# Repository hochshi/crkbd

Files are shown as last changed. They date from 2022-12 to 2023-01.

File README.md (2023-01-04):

# Corne keyboard

The Corne Choc-mini keyboard is a split keyboard with 3x5 column staggered keys
and 3 thumb keys, based on [Corne](https://github.com/foostan/crkbd). The inspiration came from David Barr's [Choc-Spaced-Corne](https://github.com/davidphilipbarr/Choc-Spaced-Corne).

## Lineup
- corne-light: 
  Light-weight Corne for choc-mini switches with choc spacing (Easy build with a simple PCB).
- corne-light-track-point: 
  Light-weight Corne for choc-mini switches with choc spacing and a trackpoint under the right thumb (or far-index) (Not ready yet).

### Future Plans
The next iteration will replace one of the micro-controllers with an IO expander

## Photos
light_01
light_02

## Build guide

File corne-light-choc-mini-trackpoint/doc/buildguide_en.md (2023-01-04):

# Build Guide

This is the Corne Light build guide.
The build guide differs depending on the version of your board,
so please choose your own from the following.

- [v1 build guide](https://github.com/foostan/crkbd/blob/master/corne-light/doc/v1/buildguide_en.md)
- [v2 low-edition build guide](https://github.com/foostan/crkbd/blob/master/corne-light/doc/v2/buildguide_low_edition_en.md)

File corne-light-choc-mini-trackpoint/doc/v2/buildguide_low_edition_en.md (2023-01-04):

# Build Guide

This is the build guide for Corne Light v2 Low edition.

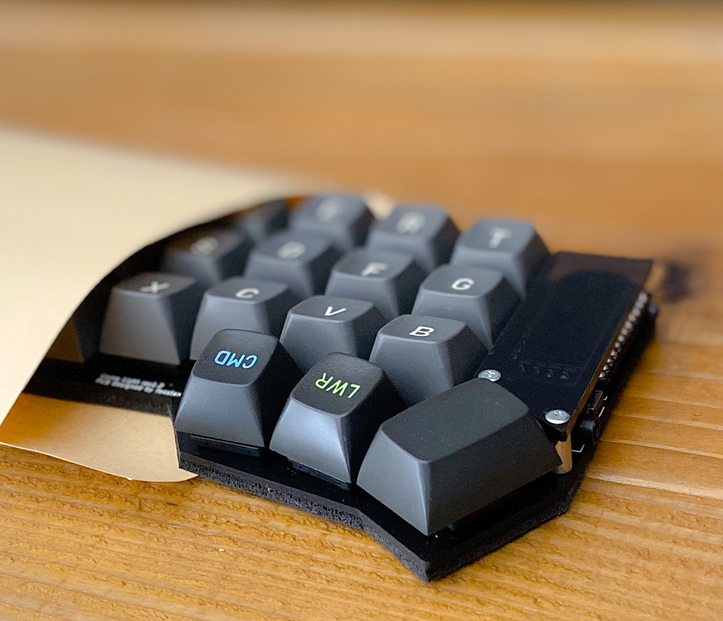
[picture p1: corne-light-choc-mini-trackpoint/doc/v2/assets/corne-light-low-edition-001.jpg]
corne-light-low-edition-001

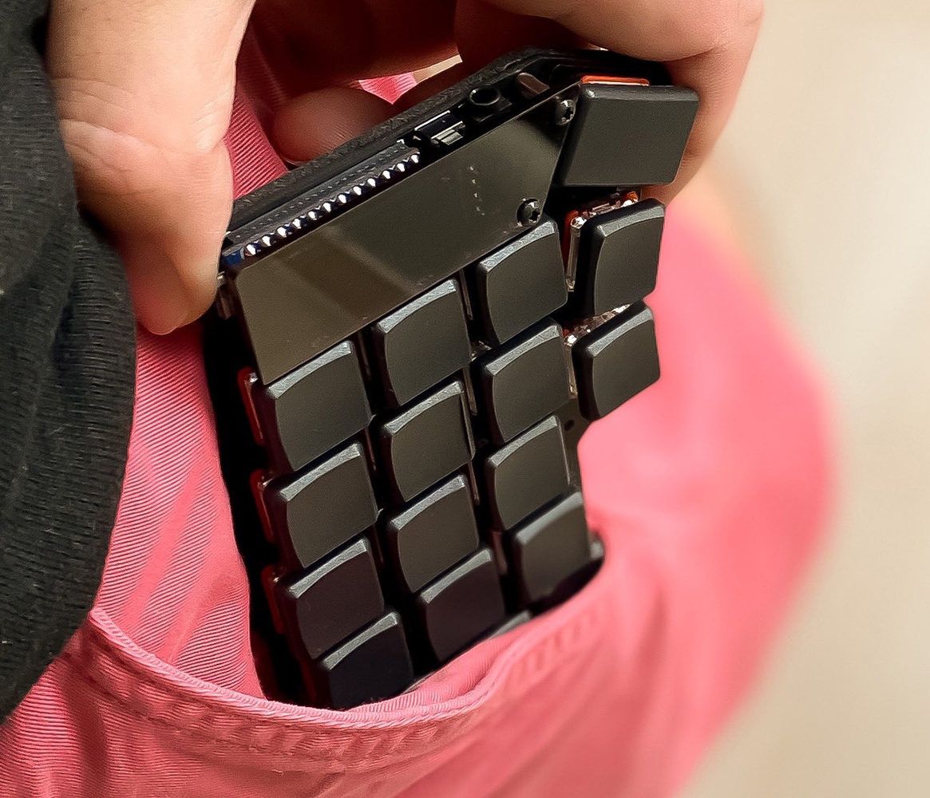
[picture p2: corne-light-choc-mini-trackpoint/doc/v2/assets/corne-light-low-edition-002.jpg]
corne-light-low-edition-002

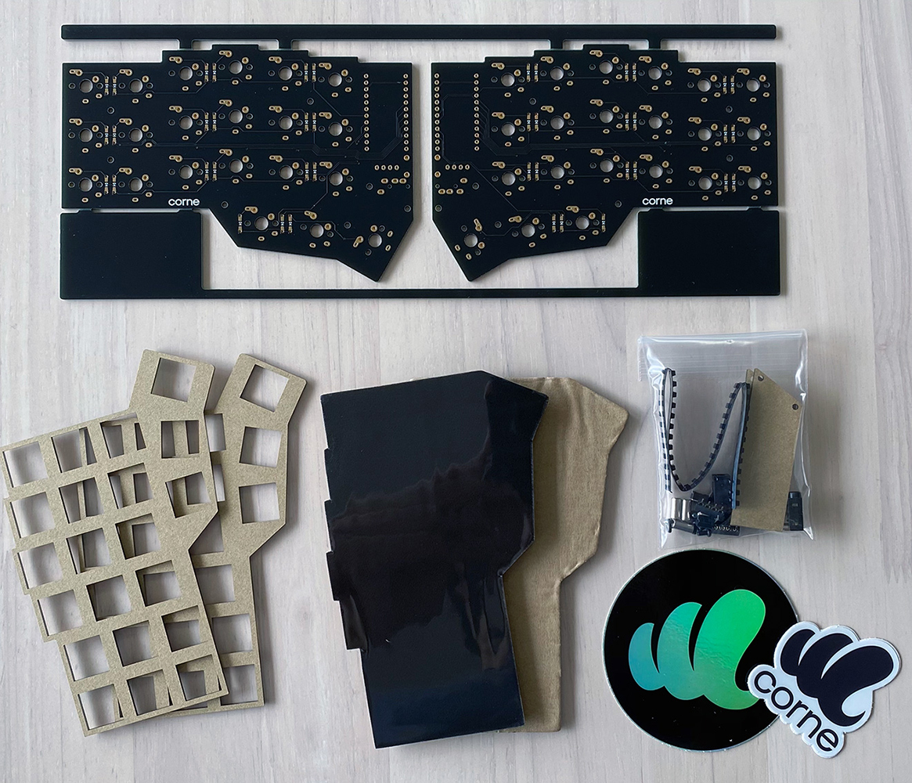
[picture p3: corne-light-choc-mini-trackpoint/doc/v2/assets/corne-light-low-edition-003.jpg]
corne-light-low-edition-003


## Parts

### Required

| Name | Count | Remarks |
|:-|:-|:-|
| PCB | 1 set | |
| Top plate (acrylic) 2mm | 2 sheets | |
| Bottom foam | 2 sheets | Special foam is cut out with a special mold |
| OLED protective plate | 2 sheets | |
| ProMicro | 2 sheets | |
| TRRS jack | 2 | |
| Tact switch | 2 | |
| Diodes | 42 | Recommended SMD Parts |
| Key switches | 42 | Kailh Choc v1 or v2 recommended |
| Keycaps | 42 pcs | 1u 40 pcs, 1.5u 2 pcs |
| Spacer M2 9mm | 4 pieces | |
| Screw M2 4mm | 8 screws | |
| TRRS (4 poles) cable | 1 | TRS (3 poles) cable is also acceptable |
| Micro USB cable | 1 | |

### Optional

| Name | Count | Remarks |
|:-|:-|:-|
| OLED module | 2 sheets | |
| Pin header for OLED module 4 series 1.5mm | 2 | |
| 4 pin sockets for OLED module 2.5mm | 2 | |

## Advance preparation

If you build the firmware yourself,
it takes time to prepare the environment,
so it is recommended to start first. \
See <https://github.com/foostan/crkbd/blob/master/doc/firmware_en.md>
for more information.

## Verification

The PCB for Corne Light v2 is as follows.
Make sure it is the same as your PCB.

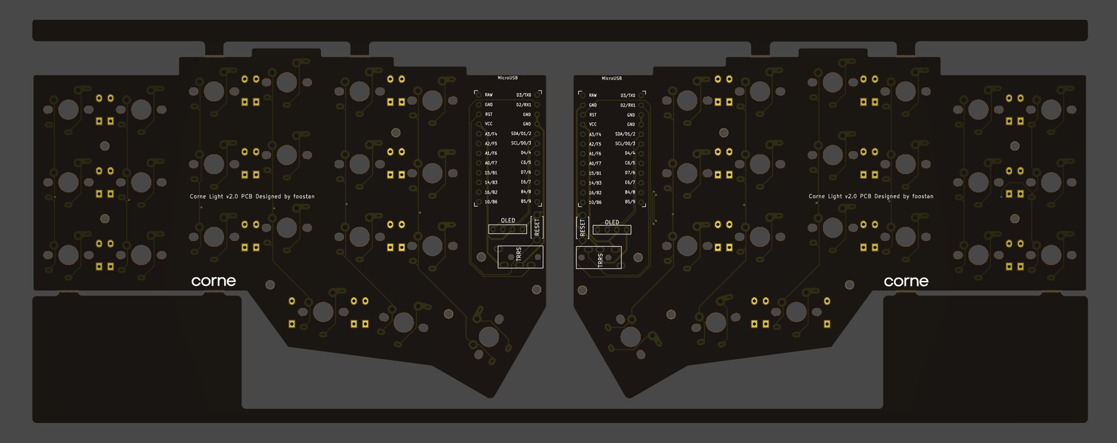
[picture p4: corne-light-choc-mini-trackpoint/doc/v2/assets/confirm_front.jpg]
confirm_front


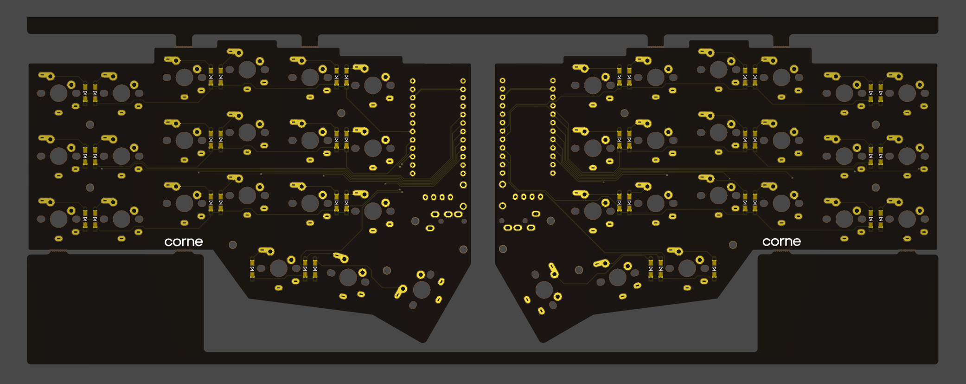
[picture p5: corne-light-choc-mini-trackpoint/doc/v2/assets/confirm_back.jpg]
confirm_back


The PCB comes with a frame for manufacturing reasons.
You can fold it by hand to remove it, but if it is difficult,
make a cut in the joint \* with a cutter or similar,
to make it easier to remove.
In addition, the joint can be cleaned with a file.

\* *Joint part: There are a total of 8 parts,
which are marked in red in the image below.*

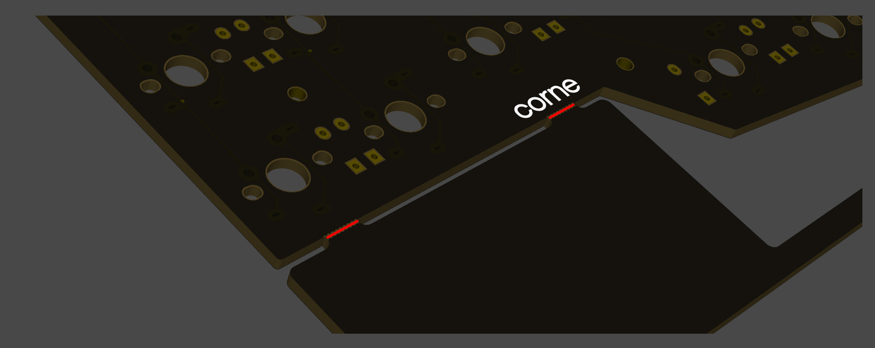
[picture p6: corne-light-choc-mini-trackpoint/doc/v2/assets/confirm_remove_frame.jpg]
confirm_remove_frame


## Assembly

### Diodes

Solder diodes for SMD components.
Since SMD parts are very small,
it is convenient to have tweezers and counter-acting tweezers.

**The diode has a fixed mounting direction**,
so solder it so that the "|" mark on the part faces the "|" on the diode mark "|◁".
In addition, Corne's PCB has all the same diode mounting orientations.

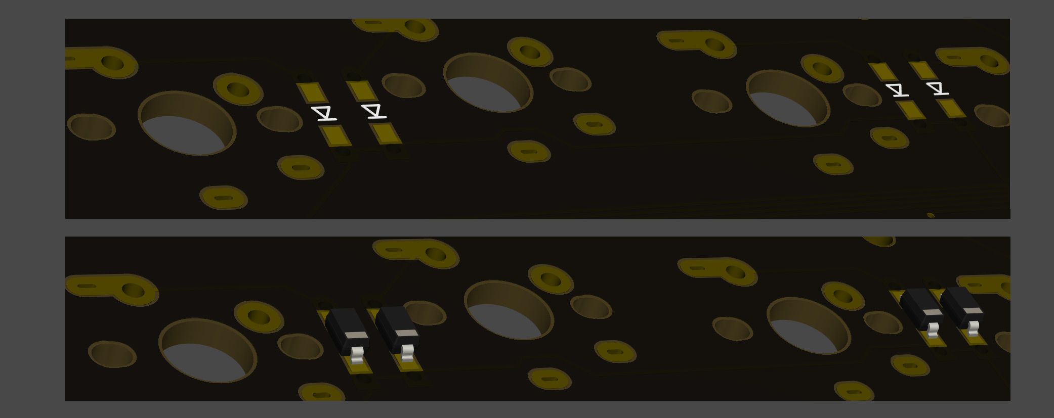
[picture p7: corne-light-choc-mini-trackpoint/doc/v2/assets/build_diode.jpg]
build_diode


<details>
<summary>TIPS: Tips for installing SMD parts</summary>

The trick is to attach the SMD parts, but first, as a spare solder,
put the solder on only one side of the pad.

tips_building_smd_01

Next, solder one leg of the diode so that the spare solder melts.
At this time, it is recommended to use reverse-action tweezers,
because you can hold the chip parts firmly without exerting force
and you can concentrate on alignment and soldering.
Also, if the soldering iron is too hot or the solder is touched too much,
the flux contained in the solder may evaporate and form a clean pile of solder,
but it can be repaired later,
so at this point you should only care about attaching parts.
It's okay.

tips_building_smd_02

It is okay if the diode does not float when viewed from the side
when one foot is attached.
If it floats, press the diode with tweezers or your fingers
and reheat the soldered part with a soldering iron to clean it.

tips_building_smd_03

Then solder the other one.
Be careful not to apply too much,
as a small amount of solder is sufficient.
If you apply too much, you can remove it with a blotting wire
or by scooping it with a soldering iron.

If the amount of solder on the preliminary solder side is small,
additional soldering is performed, and if it is a mountain,
apply flux from above and heat it to clean it.

tips_building_smd_04

</details>

The diode is completed by soldering 42 pieces in total on the left and right.

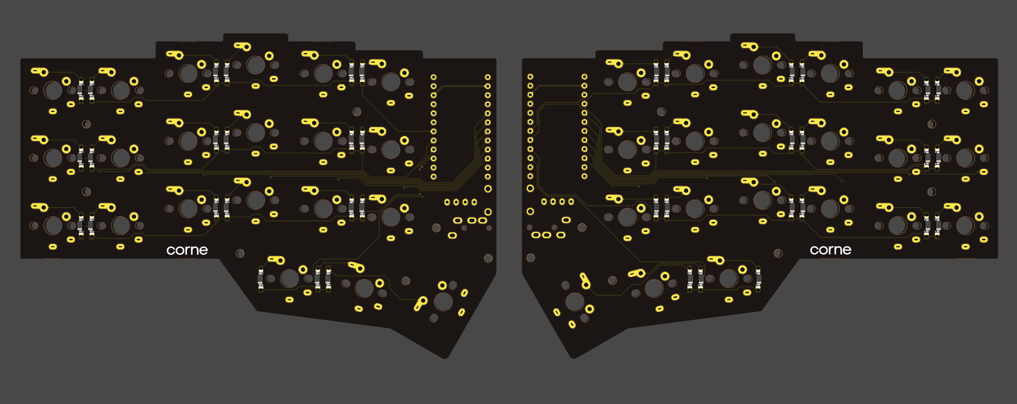
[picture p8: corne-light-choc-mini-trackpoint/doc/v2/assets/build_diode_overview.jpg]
build_diode_overview


### TRRS jack, reset switch, pin socket for OLED

Solder the TRRS jack, reset switch (tact switch),
and OLED pin socket as shown in the picture below.

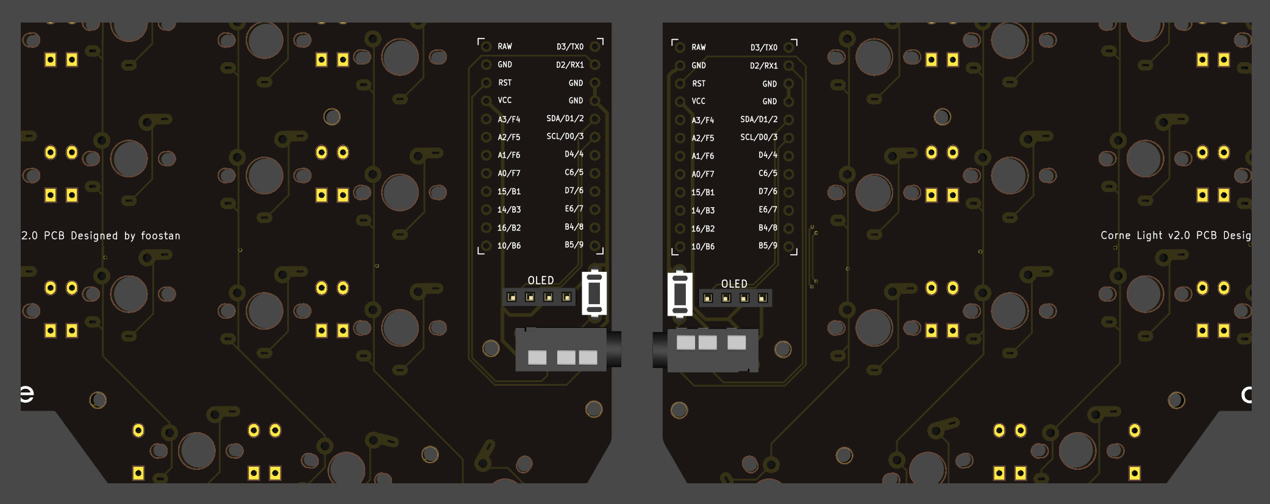
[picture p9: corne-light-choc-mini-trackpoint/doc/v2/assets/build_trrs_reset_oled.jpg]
build_trrs_reset_oled


Since it is a part that easily slips off,
you can solder it while holding the part by hand,
or fix it with masking tape and then solder it.

### ProMicro

Solder ProMicro in the following orientation

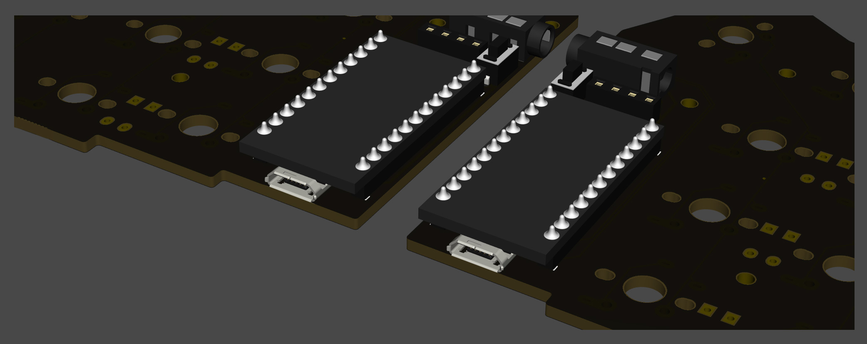
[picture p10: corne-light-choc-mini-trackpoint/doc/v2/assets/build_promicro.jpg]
build_promicro


If you use spring-loaded pin headers (e.g. Conthrough),
you do not need to solder the back side.
Please refer to the [Helix Build Guide](
https://github.com/MakotoKurauchi/helix/blob/master/Doc/buildguide_en.md#pro-micro)
for details on how to use spring-loaded pin headers.

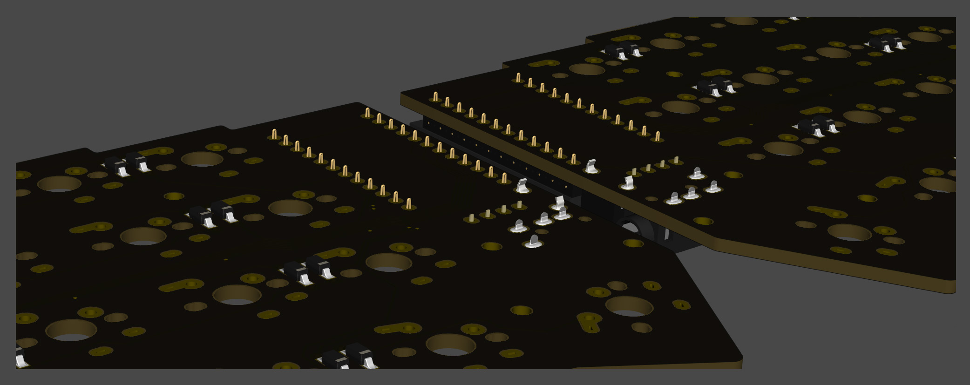
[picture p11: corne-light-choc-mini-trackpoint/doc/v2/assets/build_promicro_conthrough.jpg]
build_promicro_conthrough


### OLED module

Insert the pin header into the pin socket for OLED first,
and then solder the pin header and OLED module.
At this time, the OLED module is easy to float,
so be careful not to float it while pressing it with your finger.

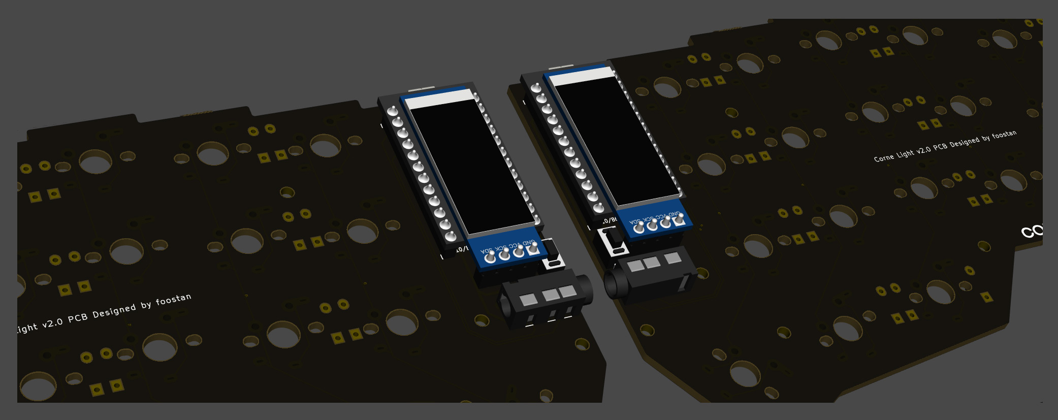
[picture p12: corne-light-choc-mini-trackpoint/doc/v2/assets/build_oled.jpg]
build_oled


### Firmware

Write the firmware to ProMicro by referring to the following. \
<https://github.com/foostan/crkbd/blob/master/doc/firmware_en.md>

### Operation check

We recommend that you check the operation when the ProMicro and OLED module are attached.
If you do it at the very end, it will be difficult to isolate the problem.

To check the operation,
connect the left hand side to the PC with MicroUSB,
and connect the left hand side and the right hand side with the TRRS cable.
Since there may be defects such as jacks,
be sure to connect the left and right instead of one by one
before checking the operation.
If it is done correctly so far,
if you short the pad to attach the PCB socket with tweezers etc.,
the key pressed on the OLED module will be displayed.

### Top plate, switch

After attaching the key switch to the top plate, solder the key switch.
If you attach all the key switches to the top plate first,
it will be more difficult to attach the switches to the board,
so it is easier to attach only the end key switches first.
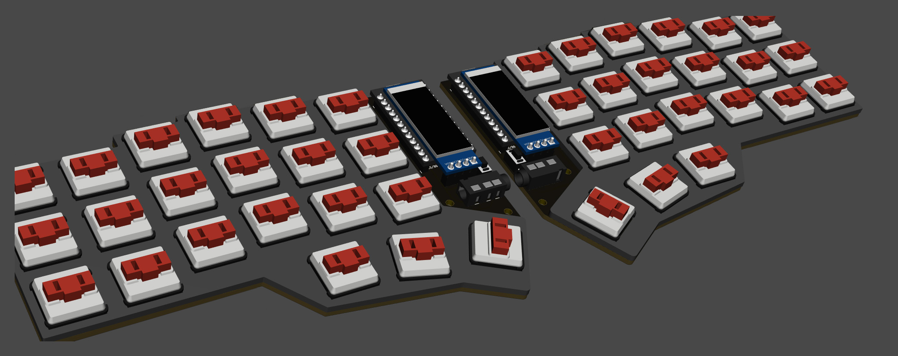
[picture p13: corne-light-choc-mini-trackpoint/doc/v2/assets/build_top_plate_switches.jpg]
build_top_plate_switches


### OLED protective plate

Attach the OLED protective plate with M2 9mm spacers and M2 screws.

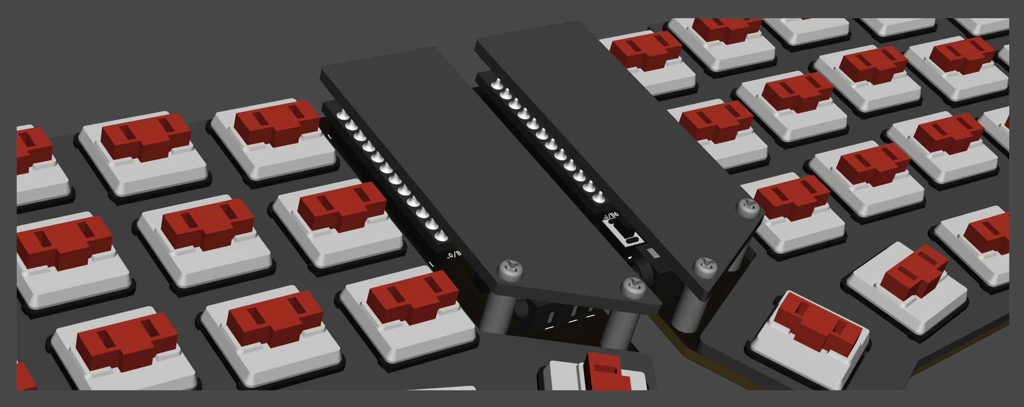
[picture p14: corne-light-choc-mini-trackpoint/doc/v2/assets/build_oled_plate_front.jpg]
build_oled_plate_front

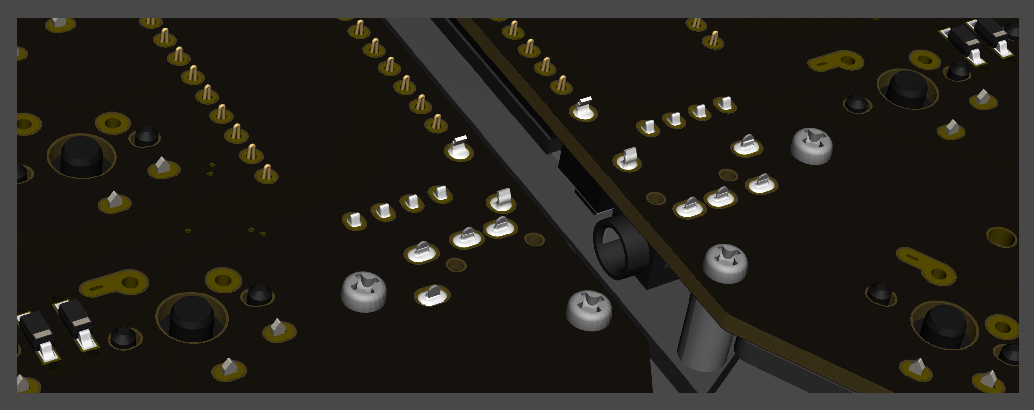
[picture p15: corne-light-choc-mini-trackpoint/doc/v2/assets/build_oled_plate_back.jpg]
build_oled_plate_back


Especially for the screws on the back side,
tighten them firmly to attach the bottom foam after this.

### Bottom form

Finally, paste the bottom form.
This foam has an adhesive surface on one side
and a non-slip surface on the other side.
Stick the adhesive side firmly to the PCB.

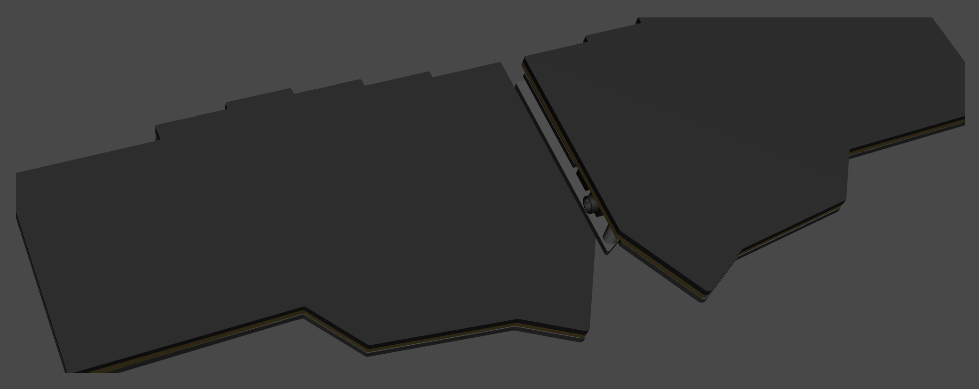
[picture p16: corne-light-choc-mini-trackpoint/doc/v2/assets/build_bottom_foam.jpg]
build_bottom_foam


That's it.

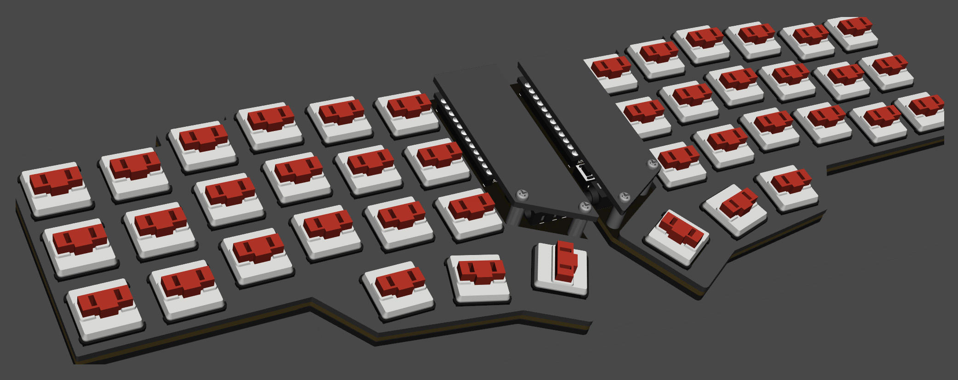
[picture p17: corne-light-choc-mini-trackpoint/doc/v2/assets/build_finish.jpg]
build_finish


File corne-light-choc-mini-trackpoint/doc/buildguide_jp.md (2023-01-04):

# Build Guide

こちらは Corne Light のビルドガイドになります。
バージョンによってビルドガイドは異なりますので、以下よりご自身のものをお選びください。

- [v1 のビルドガイドはこちら](https://github.com/foostan/crkbd/blob/master/corne-light/doc/v1/buildguide_jp.md)
- [v2 low-edition のビルドガイドはこちら](https://github.com/foostan/crkbd/blob/master/corne-light/doc/v2/buildguide_low_edition_jp.md)

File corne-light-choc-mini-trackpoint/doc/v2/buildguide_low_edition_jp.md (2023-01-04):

# Build Guide

こちらは Corne Light v2 Low edition のビルドガイドになります。

corne-light-low-edition-001
corne-light-low-edition-002
corne-light-low-edition-003

## 部品

### 必須

| 名前 | 数 | 備考 |
|:-|:-|:-|
| PCB | 1セット | |
| トッププレート(アクリル) 2mm | 2枚 | |
| ボトムフォーム | 2枚 | 特殊なフォームを専用の型で切り出しています |
| OLED保護プレート | 2枚 | |
| ProMicro | 2枚 | |
| TRRSジャック | 2個 | |
| タクトスイッチ | 2個 | |
| ダイオード | 42本 | SMD部品推奨 |
| キースイッチ | 42個 | Kailh Choc v1 or v2 推奨 |
| キーキャップ | 42個 | 1u 40個、1.5u 2個 |
| スペーサー M2 9mm | 4本 | |
| ネジ M2 4mm | 8本 | |
| TRRS(4極)ケーブル | 1本 | TRS(3極)ケーブルでも可 |
| Micro USBケーブル | 1本 | |

### オプション

| 名前 | 数 | 備考 |
|:-|:-|:-|
| OLEDモジュール | 2枚 | |
| OLEDモジュール用ピンヘッダ 4連 1.5mm | 2つ | |
| OLEDモジュール用ピンソケット 4連 2.5mm | 2つ | |

## 事前準備

ファームウェアを自分でビルドする場合は環境を整備するのに時間がかかるのではじめに取り掛かっておくことをおすすめします。\
詳しくは <https://github.com/foostan/crkbd/blob/master/doc/firmware_jp.md> を参照してください。

## 確認

Corne Light v2 のPCBは以下のものになります。お手持ちのPCBと同一のものかご確認ください。

confirm_front

confirm_back

PCBは製造の都合上フレームが付いた状態となっています。
手で折って外すことができますが、難しい場合は接合部分※にカッター等で切り込みを入れると外しやすくなります。
また、接合部分はヤスリ等できれいにすることができます。

※ 接合部分: 下記画像の赤で記した部分のこと、計8箇所あります

confirm_remove_frame

## 組み立て

### ダイオード

SMD部品のダイオードのはんだづけを行います。
SMD部品は非常に小さいためピンセット及び逆作用ピンセットがあると便利です。

**ダイオードは取り付ける向きが決まっていて**、部品の「|」印が、ダイオードマーク「|◁」の「|」の方に向けるようにはんだづけを行います。
なお、Corne の PCB はダイオードの取り付け向きがすべて統一されています。

build_diode

<details>
<summary>TIPS: SMD部品を取り付けるコツ</summary>

SMD部品を取り付けるコツですが、まずは予備ハンダとしてパットの片側のみにハンダを盛ります。

tips_building_smd_01

次に予備ハンダを溶かすようにしてダイオードの片足をはんだ付けします。
このとき、逆作用ピンセットを利用すると力を入れずともチップ部品をしっかりと持つことができ、位置合わせとはんだづけに集中できるのでおすすめです。
またはんだごてがあつすぎたり、はんだを触りすぎたりするとはんだに含まれるフラックスが気化してきれいにはんだの山ができることがありますが、あとで修復できるのでこの時点ではパーツを付けることだけを意識すれば大丈夫です。

tips_building_smd_02

片足をつけた段階で横から見てダイオードが浮いていなければ大丈夫です。浮いてしまった場合はダイオードをピンセットや指で押さえつけながらはんだごてではんだづけした部分を再度熱すればきれいになります。

tips_building_smd_03

次にもう片方をはんだづけします。少量のはんだで十分なのでつけすぎに注意します。
つけすぎてしまった場合は吸い取り線で取るか、はんだごてですくうようにすれば取れます。

また予備はんだ側のはんだの量が少ない場合は追加ではんだづけを重ねて行い、山になっている場合はフラックスを上から塗って熱すればきれいになります。

tips_building_smd_04

</details>

左右合わせて42個をはんだづけしてダイオードは完了です。

build_diode_overview

### TRRSジャック、リセットスイッチ、OLED用ピンソケット

下記の写真通りにTRRSジャック、リセットスイッチ(タクトスイッチ)、OLED用ピンソケットをはんだづけします。

build_trrs_reset_oled

ずれやすい部品なので、手で部品を抑えながらはんだづけするか、マスキングテープ等で固定してからはんだづけするときれいに付きます。

### ProMicro

ProMicroを下記のような向きではんだ付けします

build_promicro

なお、コンスルーを利用する場合は裏側のはんだ付けをする必要はありません。
コンスルーの詳しい利用方法は [Helix のビルドガイド](https://github.com/MakotoKurauchi/helix/blob/master/Doc/buildguide_jp.md#pro-micro)をご参照ください。

build_promicro_conthrough

### OLEDモジュール

OLED用のピンソケットにピンヘッダを先に差し込み、その後からピンヘッダとOLEDモジュールをはんだづけします。
このときOLEDモジュールが浮きやすいので指で押さえつけながら浮かないように気をつけます。

build_oled

### ファームウェア

下記を参照しファームウェアをProMicroに書き込みます。\
<https://github.com/foostan/crkbd/blob/master/doc/firmware_jp.md>

### 動作確認

ProMicroとOLEDモジュールを付けた段階で動作確認をすることをおすすめします。
一番最後にやると問題の切り分けが難しくなります。

動作確認は左手側はMicroUSBでPCとつなぎ、左手側と右手側をTRRSケーブルで接続させて行います。ジャック等の不良等もありえるので、片方ずつではなく必ず左右を接続させてから動作確認をしてください。ここまで正しくできていれば、PCBソケットを取り付けるパットをピンセット等でショートさせるとOLEDモジュールに押されたキーが表示されます。

### トッププレート、スイッチ

トッププレートにキースイッチに取り付けた後、キースイッチをはんだ付けします。
先にすべてのキースイッチをトッププレートに取り付けてしまうと、スイッチを基板にはめる難易度が上がってしまうため、先に端のキースイッチのみを取り付ける方が簡単です。
build_top_plate_switches

### OLED保護プレート

M2 9mm のスペーサーと M2 ネジで OLED 保護プレートを取り付けます。

build_oled_plate_front
build_oled_plate_back

特に裏側のネジについては、このあとボトムフォームを貼り付けるためしっかりと締めてください。

### ボトムフォーム

最後にボトムフォームを貼り付けます。
このフォームは片側が粘着面、もう片側が滑り止め面になっています。
粘着面をPCBにしっかいと貼り付けてください。

build_bottom_foam

以上で完成です。

build_finish

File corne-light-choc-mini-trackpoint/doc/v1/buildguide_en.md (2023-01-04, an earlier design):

# Build Guide

This is the Corne Light v1 build guide.

## Parts

<table>
<thead>
  <tr> <td width = "30%"> Name </td> <td width = "15%"> Count </td> <td> Remarks </td> </tr>
</header>
<tbody>
  <tr>
    <td> PCB </td>
    <td> 1 set </td>
    <td>
      PCB
    </td>
  </tr>
  <tr>
    <td> Top plate </td>
    <td> 2 sheets </td>
    <td>
      top-plates
    </td>
  </tr>
  <tr>
    <td> Bottom plate </td>
    <td> 2 sheets </td>
    <td rowspan = "2">
      bottom-plates
    </td>
  </tr>
  <tr>
    <td> ProMicro protective plate </td>
    <td> 2 sheets </td>
  </tr>
  <tr>
    <td> diode </td>
    <td> 42 </td>
    <td>
      diodes
    </td>
  </tr>
  <tr>
    <td> Spacer M2 7.5mm </td>
    <td> 10 </td>
    <td rowspan = "3">
      screws
    </td>
  </tr>
  <tr>
    <td> Spacer M2 9mm </td>
    <td> 4 </td>
  </tr>
  <tr>
    <td> Screw M2 4mm </td>
    <td> 28 </td>
  </tr>
  <tr>
    <td> TRRS jack </td>
    <td> 2 </td>
    <td rowspan = "3">
      jacks
    </td>
  </tr>
  <tr>
    <td> Reset switch </td>
    <td> 2 </td>
  </tr>
  <tr>
    <td> Rubber feet </td>
    <td> 8 </td>
  </tr>
  <tr>
    <td> ProMicro (with conthrough) </td>
    <td> 2 </td>
    <td>
      <a href="https://yushakobo.jp/shop/promicro-spring-pinheader/"> https://yushakobo.jp/shop/promicro-spring-pinheader/ </a>
    </td>
  </tr>
  <tr>
    <td> OLED module (with pin socket) </td>
    <td> 2 </td>
    <td>
      <a href="https://yushakobo.jp/shop/oled/"> https://yushakobo.jp/shop/oled/ </a>
    </td>
  </tr>
  <tr>
    <td> key switch </td>
    <td> 42 </td>
    <td> </td>
  </tr>
  <tr>
    <td> keycap </td>
    <td> 42 </td>
    <td> </td>
  </tr>
  <tr>
    <td> TRRS cable </td>
    <td> 1 </td>
    <td> TRS cable is also acceptable </td>
  </tr>
  <tr>
    <td> USB cable </td>
    <td> 1 </td>
    <td> </td>
  </tr>
</tbody>
</table>

## Advance preparation

If you build the firmware yourself,
it takes time to prepare the environment,
so it is recommended to start first. \
See <https://github.com/foostan/crkbd/blob/master/doc/firmware_en.md>
for more information.

## Implementation

### PCB disconnection

Check the front and back and separate the left and right PCBs
(the photo is the front).

assembly-pcb

This is a jig for bending the legs of a diode.
Separate it if necessary.

assembly-tool-of-diodes

* Some versions do not have a jig.

### Diodes

First, bend the legs of the reed type diode.

* You can clean it by bending it one by one as shown in the picture,
  but it is more efficient to bend multiple pieces at the same time
  while connected to the tape.

assembly-diodes-1

Attach the diode with the bent leg to the specified position.

assembly-diodes-2

The diode has an orientation and is installed as shown in the photo.

* All the diodes to be attached are in the same orientation.

assembly-diodes-3

You can attach it neatly by fixing it with masking tape.

assembly-diodes-4

Solder from the back side.

assembly-diodes-5

If you are fixing with masking tape,
cutting your legs to the limit like this will make soldering easier.

assembly-diodes-6

With 21 one-handed and two-handed he installs 42 diodes.

assembly-diodes-7

### TRRS jack, reset switch, pin socket

Install in the specified position.

* Install the right hand side in the same position
  (be careful of mistakes on the front and back).

assembly-jacks-resets-pinsockets-1

### ProMicro, OLED module

Install his ProMicro and his OLED module by referring to the [Helix Build Guide](
https://github.com/MakotoKurauchi/helix/blob/master/Doc/buildguide_en.md#pro-micro).

assembly-promicro-oled

### Firmware

Write the firmware to ProMicro by referring to the following. \
<https://github.com/foostan/crkbd/blob/master/doc/firmware_en.md>

### Operation check

To check the operation,
connect the left hand side to the PC with a USB cable,
and connect the left hand side and the right hand side with the TRRS cable.
Since there may be defects such as jacks,
be sure to connect the left and right instead of one by one
before checking the operation.

* Since the switch is not attached,
  check the operation with tweezers as shown in the photo.

check

### Top plate, key switch

Attach the key switch to the top plate as shown in the picture.

* Be careful of the direction of the key switch.

assembly-keyswitches-1

We recommend using a 3-pin key switch.

* Even when using 5 pins, the plastic legs can be separated to make 3 pins.

assembly-keyswitches-2

Solder so that there is no gap between the switch and the PCB.

assembly-keyswitches-3
assembly-keyswitches-4

### ProMicro Protective Plate, Bottom Plate

Attach his ProMicro protective plate using an M2 9mm spacer.

assembly-plates-1

Install the bottom plate using the M2 7.5mm spacer.

assembly-plates-2

Attach the rubber feet to the four corners.

assembly-plates-3

## Complete

Attach the keycap and you're done.

assembly-finished-1
assembly-finished-2

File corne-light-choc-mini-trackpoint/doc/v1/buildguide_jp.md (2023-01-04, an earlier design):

# Build Guide

こちらは Corne Light のビルドガイドになります。

## 部品

<table>
<thead>
  <tr><td width="30%">名前</td><td width="15%">数</td><td>備考</td></tr>
</thead>
<tbody>
  <tr>
    <td>PCB</td>
    <td>1セット</td>
    <td>
      PCB
    </td>
  </tr>
  <tr>
    <td>トッププレート</td>
    <td>2枚</td>
    <td>
      top-plates
    </td>
  </tr>
  <tr>
    <td>ボトムプレート</td>
    <td>2枚</td>
    <td rowspan="2">
      bottom-plates
    </td>
  </tr>
  <tr>
    <td>ProMicro保護プレート</td>
    <td>2枚</td>
  </tr>
  <tr>
    <td>ダイオード</td>
    <td>42本</td>
    <td>
      diodes
    </td>
  </tr>
  <tr>
    <td>スペーサー M2 7.5mm</td>
    <td>10本</td>
    <td rowspan="3">
      screws
    </td>
  </tr>
  <tr>
    <td>スペーサー M2 9mm</td>
    <td>4本</td>
  </tr>
  <tr>
    <td>ネジ M2 4mm</td>
    <td>28本</td>
  </tr>
  <tr>
    <td>TRRSジャック</td>
    <td>2つ</td>
    <td rowspan="3">
      jacks
    </td>
  </tr>
  <tr>
    <td>リセットスイッチ</td>
    <td>2つ</td>
  </tr>
  <tr>
    <td>ゴム足</td>
    <td>8つ</td>
  </tr>
  <tr>
    <td>ProMicro(コンスルー付き)</td>
    <td>2つ</td>
    <td>
      <a href="https://yushakobo.jp/shop/promicro-spring-pinheader/">https://yushakobo.jp/shop/promicro-spring-pinheader/</a>
    </td>
  </tr>
  <tr>
    <td>OLEDモジュール(ピンソケット付き)</td>
    <td>2つ</td>
    <td>
      <a href="https://yushakobo.jp/shop/oled/">https://yushakobo.jp/shop/oled/</a>
    </td>
  </tr>
  <tr>
    <td>キースイッチ</td>
    <td>42個</td>
    <td></td>
  </tr>
  <tr>
    <td>キーキャップ</td>
    <td>42個</td>
    <td></td>
  </tr>
  <tr>
    <td>TRRSケーブル</td>
    <td>1本</td>
    <td>TRSケーブルでも可</td>
  </tr>
  <tr>
    <td>USBケーブル</td>
    <td>1本</td>
    <td></td>
  </tr>
</tbody>
</table>

## 事前準備

ファームウェアを自分でビルドする場合は環境を整備するのに時間がかかるのではじめに取り掛かっておくことをおすすめします。\
詳しくは <https://github.com/foostan/crkbd/blob/master/doc/firmware_jp.md> を参照してください。

## 実装

### PCBの切り離し

裏表を確認して左右のPCBを切り離します(写真は表です)。

assembly-pcb

こちらはダイオードの足を曲げるための治具です。
必要に応じて切り離しておきます。

assembly-tool-of-diodes

※　バージョンによって治具が付いていないものもあります。

### ダイオード

まずはリードタイプのダイオードの足を曲げていきます。
※ 写真のように一本ずつ曲げるときれいにできますが、テープに繋がれたまま複数本を同時に曲げたほうが効率的です。

assembly-diodes-1

足を曲げたダイオードを指定の位置に付けていきます。

assembly-diodes-2

ダイオードには向きがあり、写真のように取り付けます。
※ 取り付けるダイオードはすべて同じ向きです。

assembly-diodes-3

マスキングテープで固定するときれいに付けることができます。

assembly-diodes-4

裏面からはんだ付けを行います。

assembly-diodes-5

マスキングテープで固定している場合はこのようにギリギリまで足を切るとはんだ付けがやりやすくなります。

assembly-diodes-6

片手21個、両手分で 42 個のダイオードを取り付けます。

assembly-diodes-7

### TRRSジャック、リセットスイッチ、ピンソケット

指定の位置に取り付けます。
※ 右手側も同じ位置に取り付けます(表裏の間違いに気を付けてください)。

assembly-jacks-resets-pinsockets-1

### ProMicro、OLEDモジュール

[Helix のビルドガイド](https://github.com/MakotoKurauchi/helix/blob/master/Doc/buildguide_jp.md#pro-micro)を参考にして ProMicro および OLED モジュールを取り付けます。

assembly-promicro-oled

### ファームウェアの書き込み

下記を参照しファームウェアをProMicroに書き込みます。\
<https://github.com/foostan/crkbd/blob/master/doc/firmware_jp.md>

### 動作確認

動作確認は左手側を USB ケーブルで PC とつなぎ、左手側と右手側を TRRS ケーブルで接続して行います。ジャック等の不良もありえるので、片方ずつではなく必ず左右を接続させてから動作確認をしてください。
※ スイッチを付けてないので写真のようにピンセット等で動作確認を行います。

check

### トッププレート、キースイッチ

写真のようにトッププレートにキースイッチをはめます。
※ キースイッチの向きに気を付けてください。

assembly-keyswitches-1

キースイッチは3ピンのものをおすすめします。
※ 5ピンを使用する場合でもプラスチックの足を切り離して3ピンにすることができます。

assembly-keyswitches-2

スイッチとPCBの間に隙間ができないようにしてはんだ付けを行います。

assembly-keyswitches-3
assembly-keyswitches-4

### ProMicro 保護プレート、ボトムプレート

M2 9mm スペーサーを用いて ProMicro 保護プレートを取り付けます。

assembly-plates-1

M2 7.5mm スペーサーを用いてボトムプレートを取り付けます。

assembly-plates-2

4つ角にゴム足を取り付けます。

assembly-plates-3

## 完成

キーキャップを取り付けて完成です。

assembly-finished-1
assembly-finished-2

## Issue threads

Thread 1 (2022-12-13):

Fix diode spacing

hochshi, 2022-12-13:
Diodes need to moved away for the pg1232 footprint and be placed on the outer lines themselves.
The current location might cause clearance issues between the diodes and switches.

See for measurements: [pg1232 schematics](https://images.anandtech.com/doci/11851/1232.jpg).
In a nutshell the switch external housing is 14.50x13.05.

hochshi, 2023-01-09:
Built a keyboard using the current spacing, luckily it works though requires careful placement.

Closed 2023-01-09.

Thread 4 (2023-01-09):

Can I2C be used reliably?

hochshi, 2023-01-09:
I2C might have issues with cables over 50 cm.
The order of wires matters - see NXP user guide.
Wiring should be:
SDA
VDD
VSS
SCL

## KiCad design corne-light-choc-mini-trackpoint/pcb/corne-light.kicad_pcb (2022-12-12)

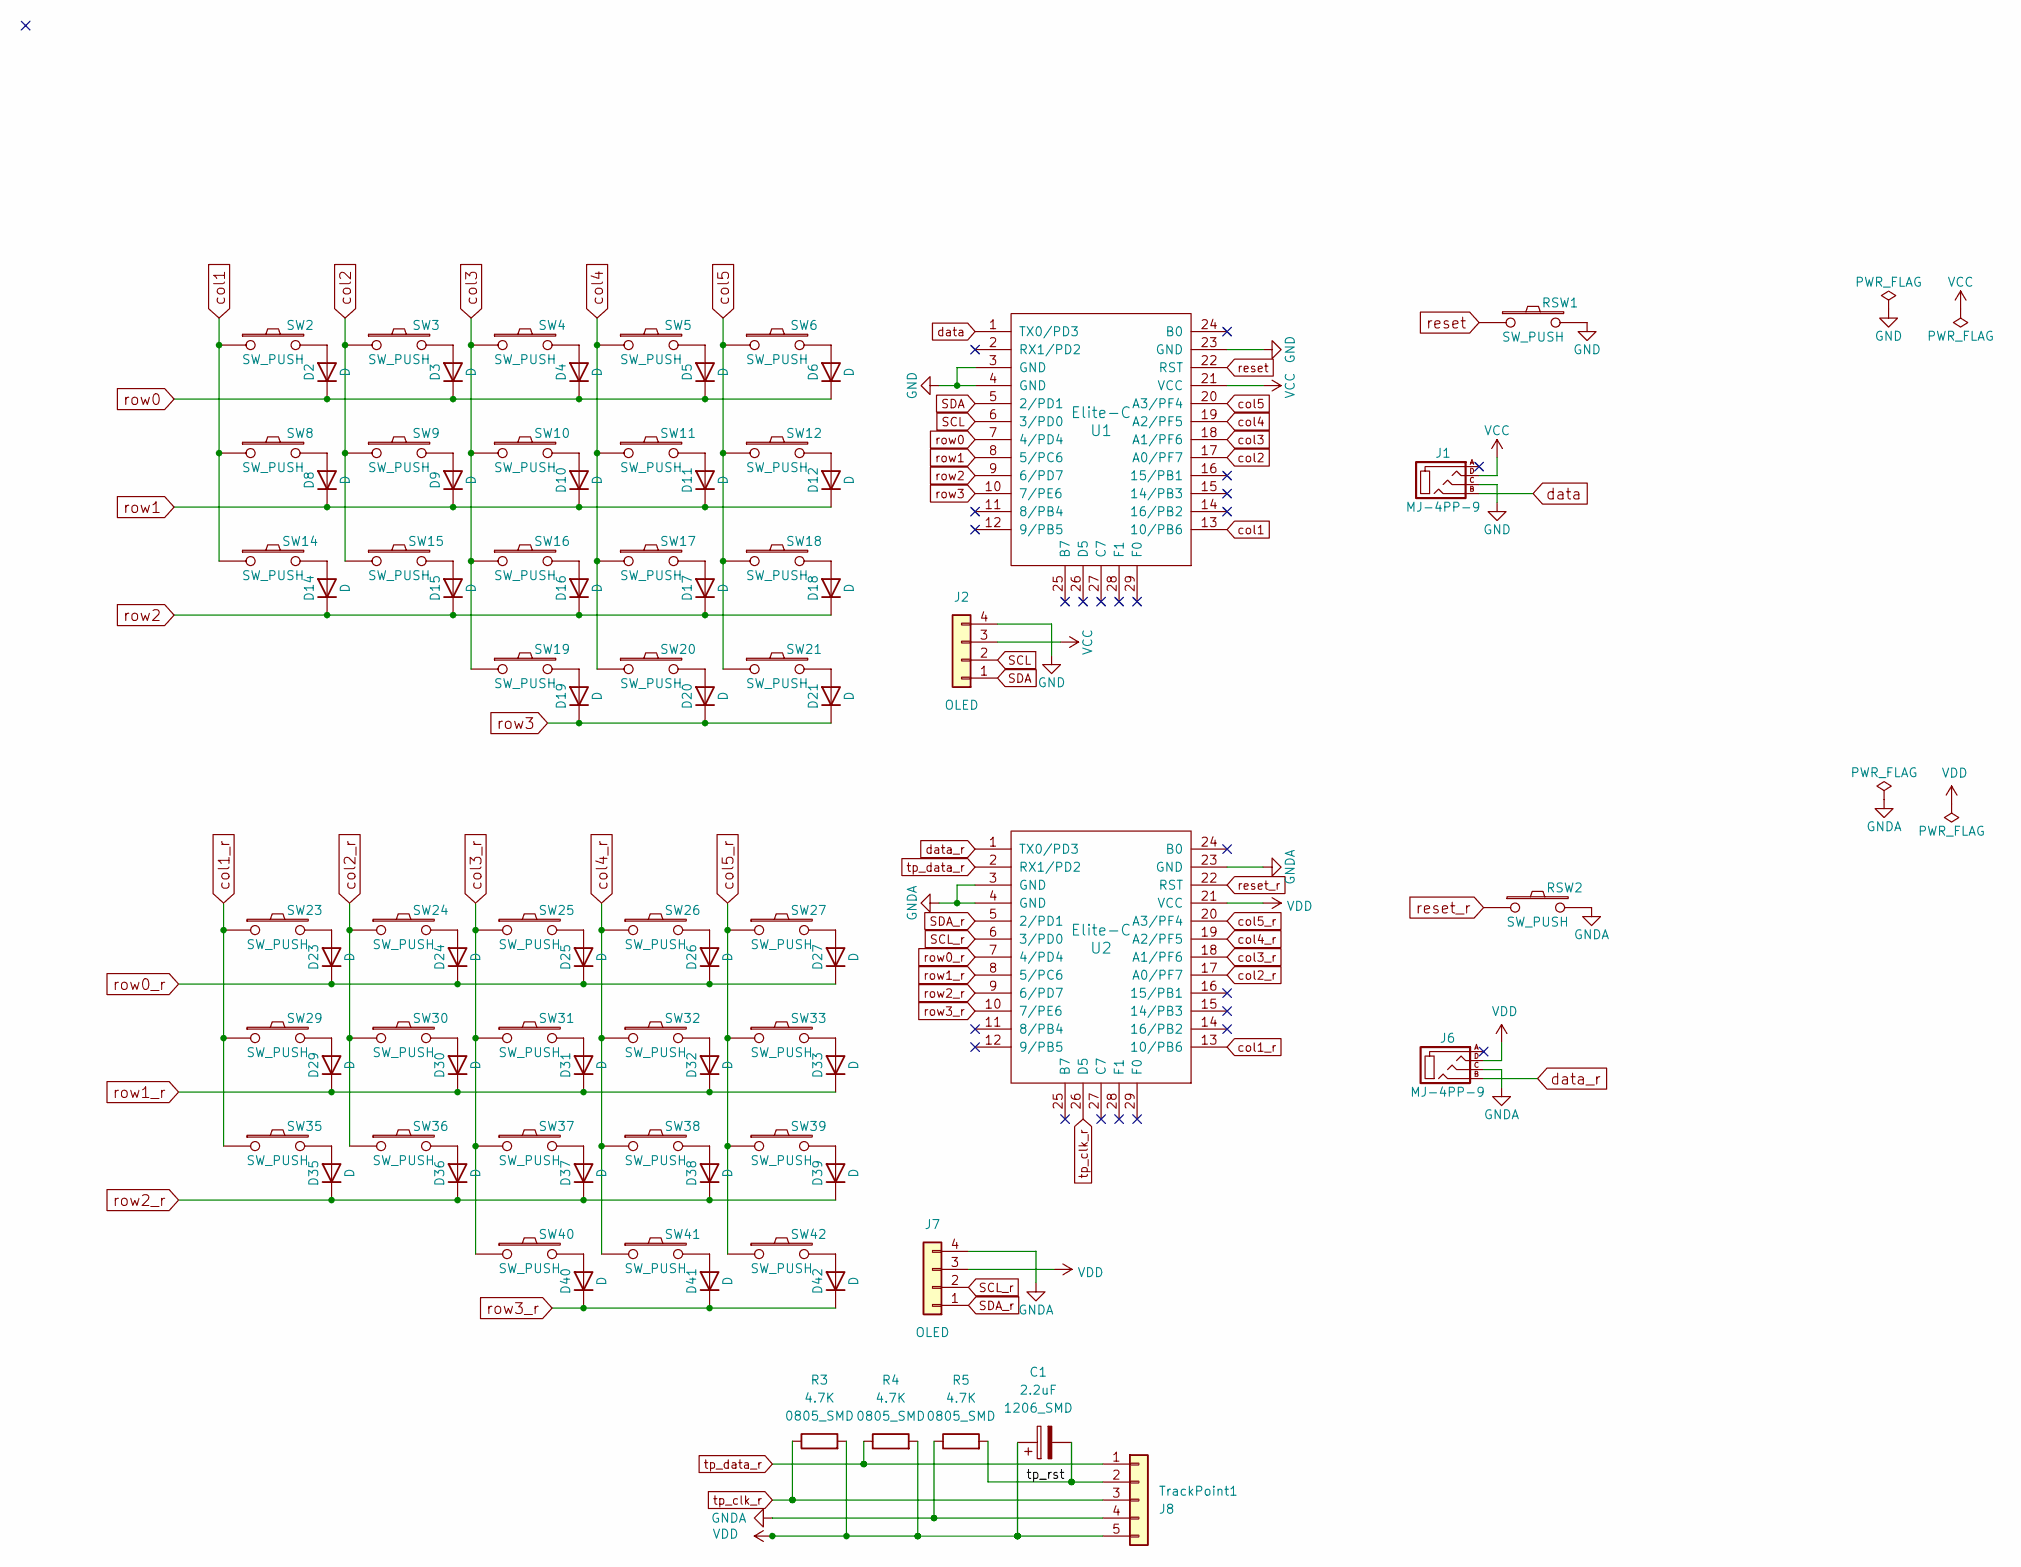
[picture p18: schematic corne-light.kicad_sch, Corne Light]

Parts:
C1: 2.2uF; C_1206_3216Metric
D2, D3, D4, D5, D6, D8, D9, D10, D11, D12, D14, D15, D16, D17, D18, D19, D20, D21, D23, D24, D25, D26, D27, D29, D30, D31, D32, D33, D35, D36, D37, D38, D39, D40, D41, D42: D; D3_TH
J1, J6: MJ-4PP-9; MJ-4PP-9_1side
J2, J7: OLED; OLED_1side
R3, R4, R5: 4.7K; R_0805_2012Metric
RSW1, RSW2: SW_PUSH; ResetSW_1side
SW2, SW3, SW4, SW5, SW6, SW8, SW9, SW10, SW11, SW12, SW14, SW15, SW16, SW17, SW18, SW19, SW20, SW21, SW23, SW24, SW25, SW26, SW27, SW29, SW30, SW31, SW32, SW33, SW35, SW36, SW37, SW38, SW39, SW40, SW41, SW42: SW_PUSH; Kailh_PG1232
TrackPoint1: J8; PinHeader_1x05_P2.54mm_Vertical
U1, U2: Elite-C

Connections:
/tp_rst: C1.2, R5.2, TrackPoint1.2; also elsewhere on the board
GND: J1.C, J2.4, RSW1.2, U1.3 (GND), U1.4 (GND), U1.23 (GND)
GNDA: J6.C, J7.4, R5.1, RSW2.2, TrackPoint1.4, U2.3 (GND), U2.4 (GND), U2.23 (GND); also elsewhere on the board
unnamed: D2.2 (A), SW2.2
unnamed: D3.2 (A), SW3.2
unnamed: D4.2 (A), SW4.2
unnamed: D5.2 (A), SW5.2
unnamed: D6.2 (A), SW6.2
unnamed: D8.2 (A), SW8.2
unnamed: D9.2 (A), SW9.2
unnamed: D10.2 (A), SW10.2
unnamed: D11.2 (A), SW11.2
unnamed: D12.2 (A), SW12.2
unnamed: D14.2 (A), SW14.2
unnamed: D15.2 (A), SW15.2
unnamed: D16.2 (A), SW16.2
unnamed: D17.2 (A), SW17.2
unnamed: D18.2 (A), SW18.2
unnamed: D19.2 (A), SW19.2
unnamed: D20.2 (A), SW20.2
unnamed: D21.2 (A), SW21.2
unnamed: D23.2 (A), SW23.2
unnamed: D24.2 (A), SW24.2
unnamed: D25.2 (A), SW25.2
unnamed: D26.2 (A), SW26.2
unnamed: D27.2 (A), SW27.2
unnamed: D29.2 (A), SW29.2
unnamed: D30.2 (A), SW30.2
unnamed: D31.2 (A), SW31.2
unnamed: D32.2 (A), SW32.2
unnamed: D33.2 (A), SW33.2
unnamed: D35.2 (A), SW35.2
unnamed: D36.2 (A), SW36.2
unnamed: D37.2 (A), SW37.2
unnamed: D38.2 (A), SW38.2
unnamed: D39.2 (A), SW39.2
unnamed: D40.2 (A), SW40.2
unnamed: D41.2 (A), SW41.2
unnamed: D42.2 (A), SW42.2
SCL: J2.2, U1.6 (3/PD0)
SCL_r: J7.2, U2.6 (3/PD0)
SDA: J2.1, U1.5 (2/PD1)
SDA_r: J7.1, U2.5 (2/PD1)
VCC: J1.D, J2.3, U1.21 (VCC)
VDD: C1.1, J6.D, J7.3, R3.2, R4.2, TrackPoint1.5, U2.21 (VCC); also elsewhere on the board
col1: SW2.1, SW8.1, SW14.1, U1.13 (10/PB6)
col1_r: SW23.1, SW29.1, SW35.1, U2.13 (10/PB6)
col2: SW3.1, SW9.1, SW15.1, U1.17 (A0/PF7)
col2_r: SW24.1, SW30.1, SW36.1, U2.17 (A0/PF7)
col3: SW4.1, SW10.1, SW16.1, SW19.1, U1.18 (A1/PF6)
col3_r: SW25.1, SW31.1, SW37.1, SW40.1, U2.18 (A1/PF6)
col4: SW5.1, SW11.1, SW17.1, SW20.1, U1.19 (A2/PF5)
col4_r: SW26.1, SW32.1, SW38.1, SW41.1, U2.19 (A2/PF5)
col5: SW6.1, SW12.1, SW18.1, SW21.1, U1.20 (A3/PF4)
col5_r: SW27.1, SW33.1, SW39.1, SW42.1, U2.20 (A3/PF4)
data: J1.B, U1.1 (TX0/PD3)
data_r: J6.B, U2.1 (TX0/PD3)
reset: RSW1.1, U1.22 (RST)
reset_r: RSW2.1, U2.22 (RST)
row0: D2.1 (K), D3.1 (K), D4.1 (K), D5.1 (K), D6.1 (K), U1.7 (4/PD4)
row0_r: D23.1 (K), D24.1 (K), D25.1 (K), D26.1 (K), D27.1 (K), U2.7 (4/PD4)
row1: D8.1 (K), D9.1 (K), D10.1 (K), D11.1 (K), D12.1 (K), U1.8 (5/PC6)
row1_r: D29.1 (K), D30.1 (K), D31.1 (K), D32.1 (K), D33.1 (K), U2.8 (5/PC6)
row2: D14.1 (K), D15.1 (K), D16.1 (K), D17.1 (K), D18.1 (K), U1.9 (6/PD7)
row2_r: D35.1 (K), D36.1 (K), D37.1 (K), D38.1 (K), D39.1 (K), U2.9 (6/PD7)
row3: D19.1 (K), D20.1 (K), D21.1 (K), U1.10 (7/PE6)
row3_r: D40.1 (K), D41.1 (K), D42.1 (K), U2.10 (7/PE6)
tp_clk_r: R3.1, TrackPoint1.3, U2.26 (D5); also elsewhere on the board
tp_data_r: R4.1, TrackPoint1.1, U2.2 (RX1/PD2); also elsewhere on the board

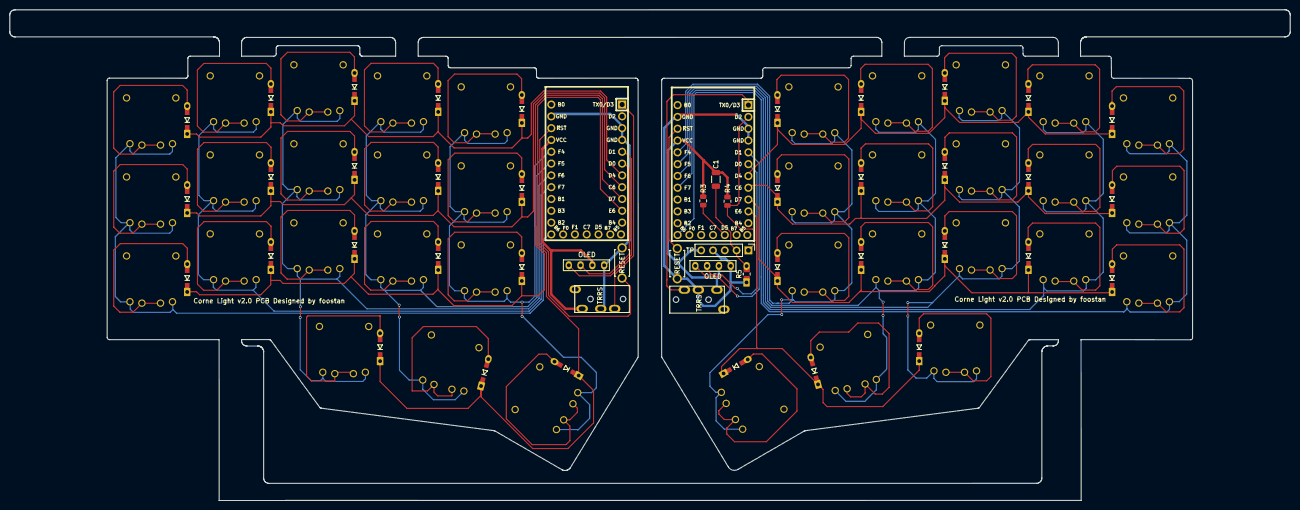
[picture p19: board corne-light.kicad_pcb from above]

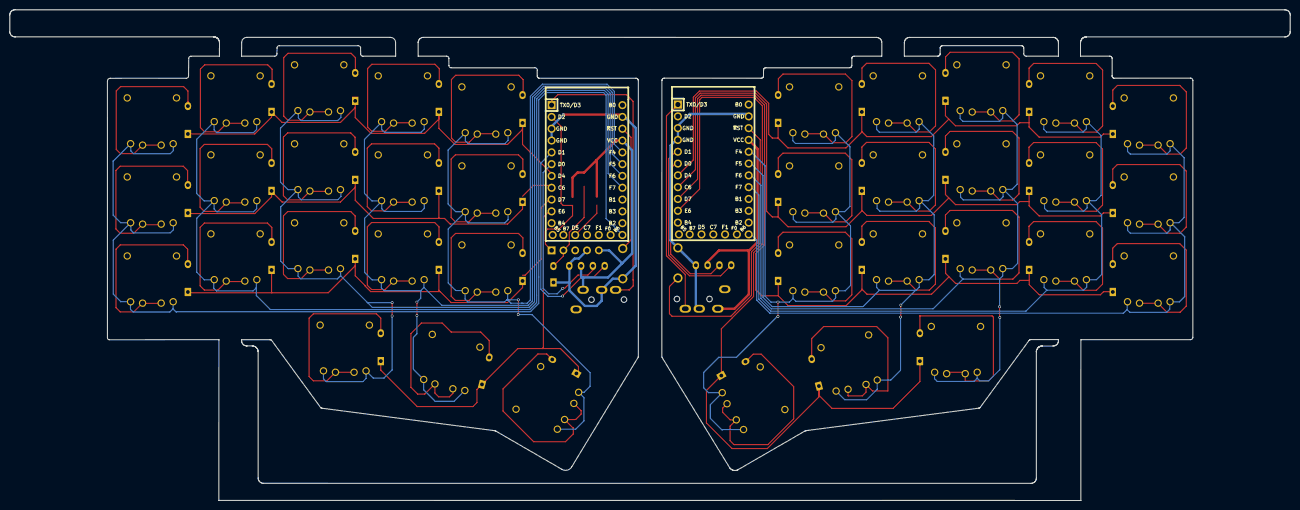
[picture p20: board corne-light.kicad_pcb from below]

Board: 2 copper layers, 275.5 x 105.6 mm, 85 parts (2 on the bottom side), 69 nets.

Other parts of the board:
TP: J8; PinHeader_1x05_P2.54mm_Vertical

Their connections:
/tp_rst: TP.2; also elsewhere on the board
GNDA: TP.4; also elsewhere on the board
VDD: TP.5; also elsewhere on the board
tp_clk_r: TP.3; also elsewhere on the board
tp_data_r: TP.1; also elsewhere on the board

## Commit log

2022-12-12 Added track pad support with reset board soldered on the pcb
    [corne-light.kicad_pcb, corne-light.kicad_sch]
2023-01-04 Added corne-light choc-mini trackpoint
    [corne-light.kicad_pcb, corne-light.kicad_sch, corne-light.sch]
2023-01-04 Fixed typo in dir names
    [corne-light.kicad_pcb, corne-light.kicad_sch, corne-light.sch]
2023-01-04 Added keebio's component and footprints
